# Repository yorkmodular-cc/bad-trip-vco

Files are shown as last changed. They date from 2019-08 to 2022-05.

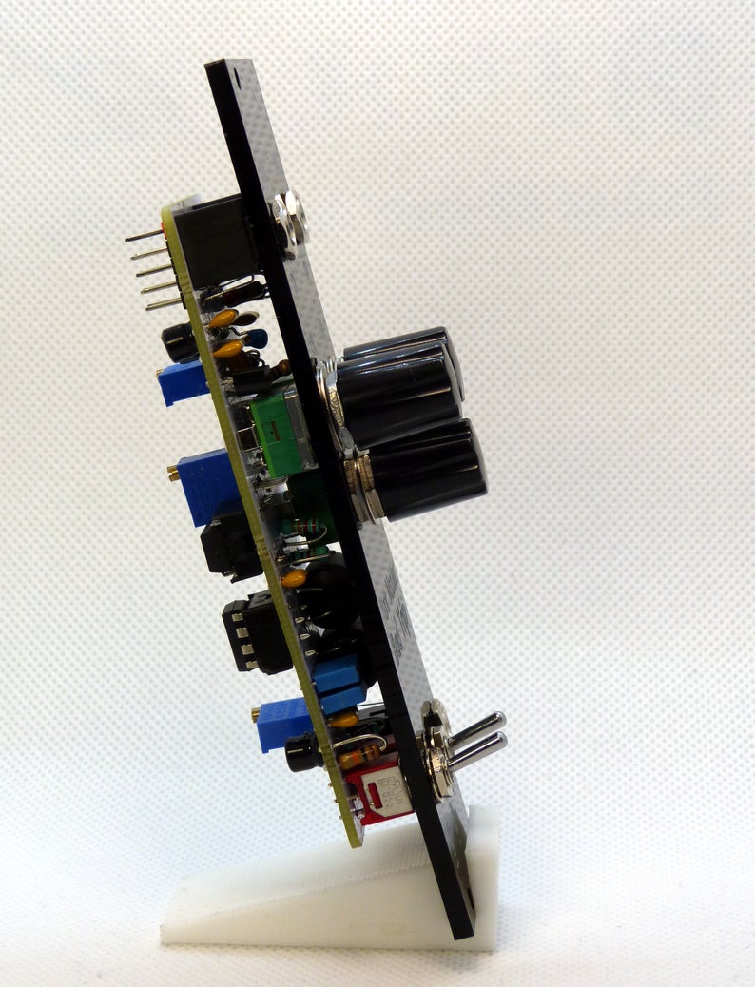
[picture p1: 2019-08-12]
images/il_794xN.1995096913_r65r.jpg

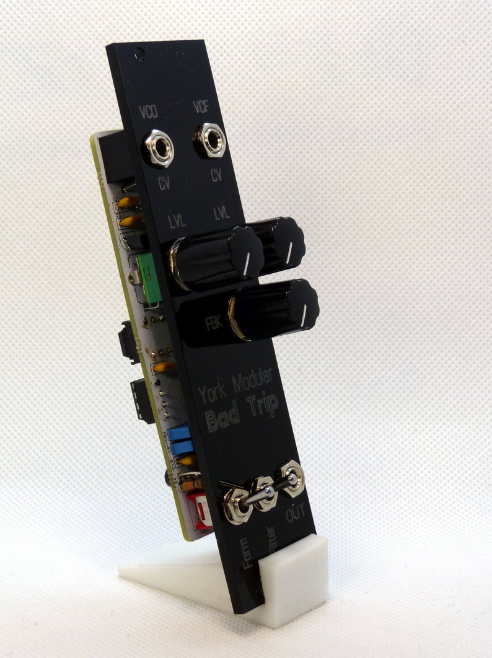
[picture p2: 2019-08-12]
images/il_794xN.1947558196_pjqa.jpg

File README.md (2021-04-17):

## York Modular 'Bad Trip' VCO

**This module is now discontinued - there will be no more made unless there is sufficient demand to justify a new run of boards and panels.**

**Information provided here is provided under the terms of the Creative Commons License Attribution-ShareAlike 4.0 International**

These are the files that you may (or may not) need for the Bad Trip VCO kit. It is assumed that you have enough knowledge to source appropriate components and read a schematic. 

Knowledge of how to use the Arduino IDE (or equivalent) to flash an ATTiny45/85 MCU is also desireable but not essential. In order to flash the firmware, your Arduino setup will need to include the ATTiny core by David Mellis - you can download that at https://github.com/damellis/attiny or install it via the Board Manager on newer versions of the Arduino IDE. As is, the default firmware will fit onto an ATTiny45 with space to spare - when flashing the firmware you'll need to specify the appropriate MCU with a 16MHz internal clock. Whilst there's absolutely no reason why you can't use a different clock speed, the frequency lookup table values assume a clock speed of 16MHz

The 'Bad Trip' is a square/saw VCO with a built in resonant vactrol filter - it gets it's name from the fact that you can coax some pretty squonky acid-style basslines out of it on the one hand, and utterly godawful nightmare noises on the other. 

More fun than it sounds, really.

Files included are:

- `badtrip-schematic.png` - the board schematic.
- `badtrip-bom.xlsx` - the Bill of Materials (BOM); this is a list of all the bits you'll need to complete the build.
- The `panels` directory contains design files for the front panel in AutoCAD (`.dxf`) and Schaeffer (`.fpd`) formats. You'll need these if you plan to fab your own panels.
- The `src` directory contains the firmware source file and a corresponding `.hex` file.
- `gerbers` contains the Gerber file for fabrication. These are what you want to be sending to the fab.

The firmware has a permissive license, so feel free to hack on it - all pull requests will be considered.

### Construction

There are no particular gotchas in terms of construction, however you should consider the following when setting the module up:

- Trimmer R7 controls the amount of current flowing into the two filter vactrols.
- Trimmers R10 and R11 affect the 'maximum' resistance of the two filter vactrols. They don't necessarily need to be trimmed to the same value - indeed, you'll get more interesting sounds out if they aren't.
- The effect of the feedback resistor will depend on the values of R10 and R11; in a lot of cases the response is somewhat 'digital' - if you're building from scratch then you can replace this pot with a wire link (and make sure you remove the corresponding hole from the panel)

### IMPORTANT

Since the VCO is microcontroller-based there are limits to the range of CV voltages that can be handled - anything negative is 'rejected' (ie. treated as 0V) whereas anything above 5V is clipped to 5V - the net result is that the VCO has a range of 5 octaves. Under most circumstances you'll want to have the CV pot fully clockwise, however if you're outputting particularly 'hot' CVs then you'll need to fiddle with the CV attenuator to bring the incoming CV down to something that the MCU can handle.

By default, the lowest note output by the VCO is C1 (32Hz) - you can alter this in firmware by modifying the frequency lookup table.

The tracking is pretty decent over 5 octaves but suffers a little due to the resolution of the ATTiny's ADC (10 bits) - this means that the input range is split into 1024 'divisions', with each division corresponding to around 4mV. If you want super-accurate to-the-cent tuning then you might well be disappointed, although you could probably fix things up in the firmware to a certain extent - this is where most of the work is done anyway.

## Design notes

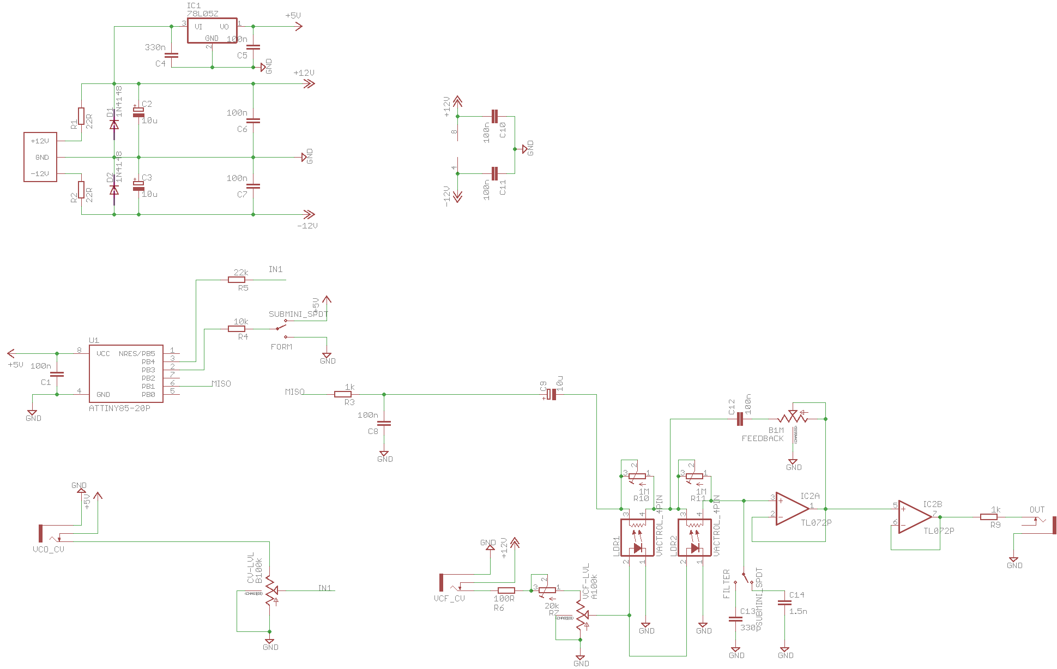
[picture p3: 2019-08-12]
badtrip-schematic.png

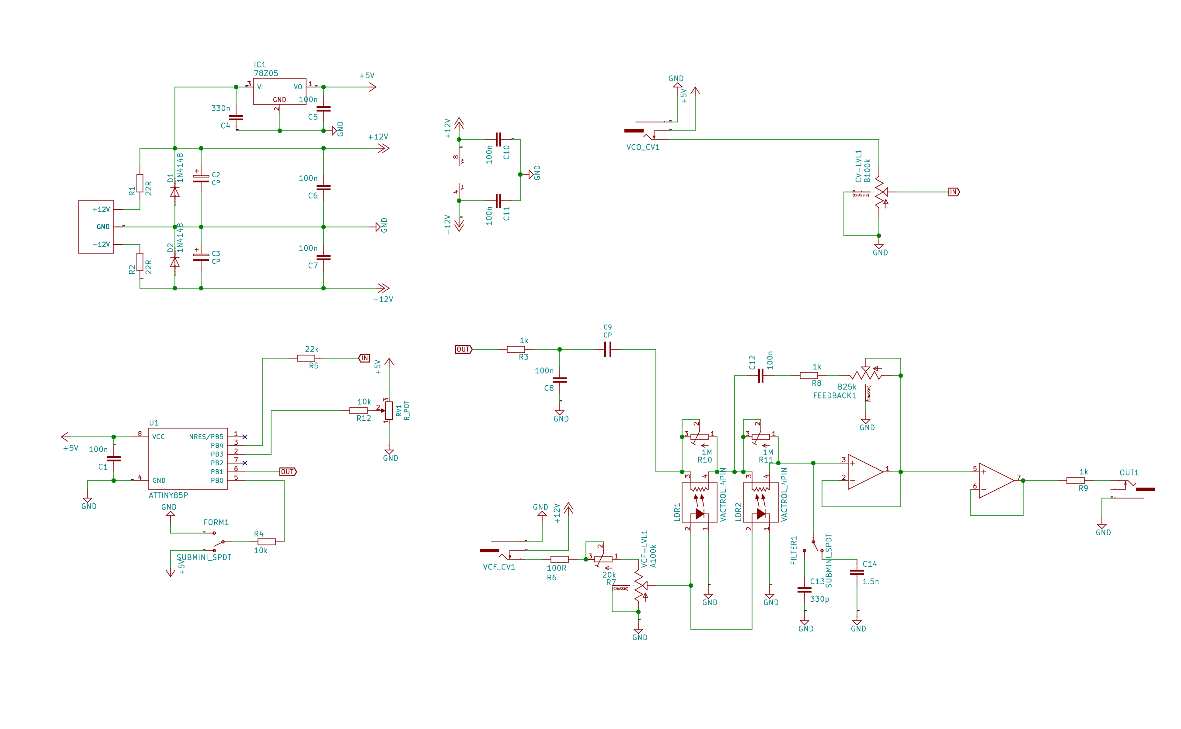
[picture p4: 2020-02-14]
v1.5/badtrip-1.5-schematic.png

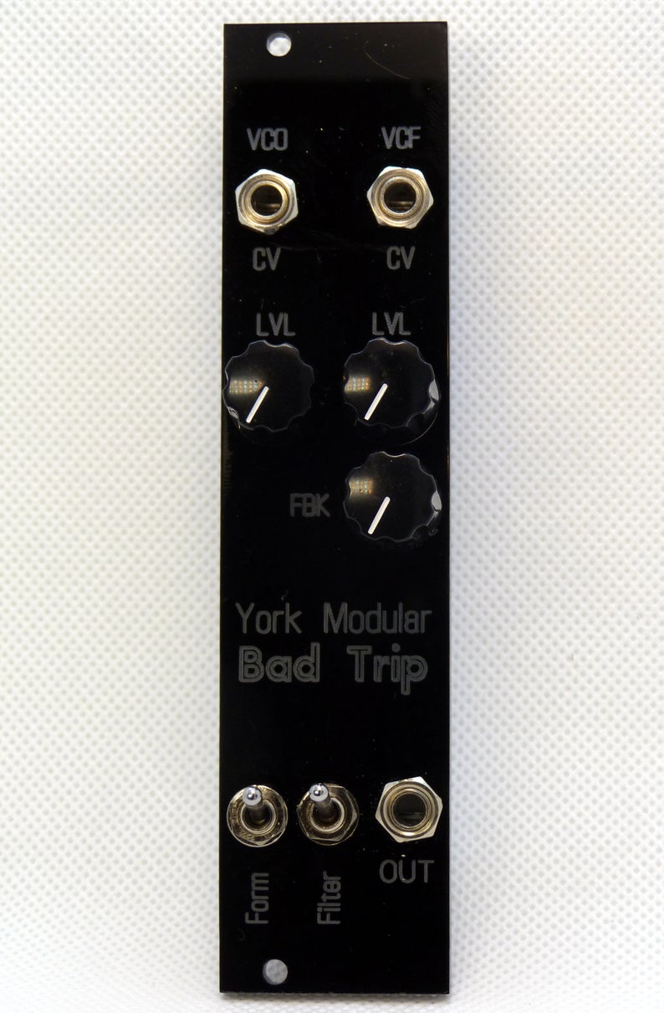
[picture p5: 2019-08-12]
images/il_794xN.1995097203_pyxm.jpg

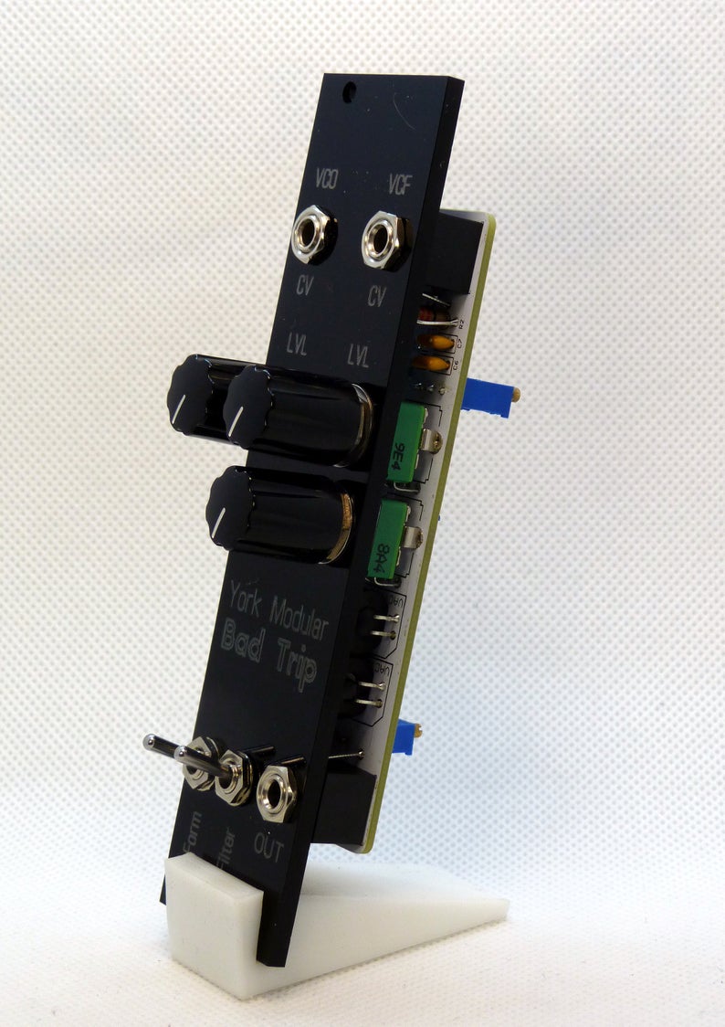
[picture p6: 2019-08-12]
images/il_794xN.1950445388_aedu.jpg

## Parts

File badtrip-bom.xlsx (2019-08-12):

Qty | Value | Device | Package | Parts | Description
1 | 1.5n | C-EU025-025X050 | C025-025X050 | C14 | CAPACITOR, European symbol
1 | 100R | R-EU_0207/2V | 0207/2V | R6 | RESISTOR, European symbol
6 | 100n | C-EU025-025X050 | C025-025X050 | C1, C5, C6, C7, C10, C11 | CAPACITOR, European symbol
2 | 100n | C-EU050-025X075 | C050-025X075 | C8, C12 | CAPACITOR, European symbol
1 | 10k | R-EU_0207/2V | 0207/2V | R4 | RESISTOR, European symbol
3 | 10u | CPOL-EUE2.5-5 | E2,5-5 | C2, C3, C9 | POLARIZED CAPACITOR, European symbol
2 | 1M | R-TRIMM3296W | RTRIM3296W | R10, R11 | Trimm resistor
2 | 1N4148 | DIODE-D-2.5 | D-2.5 | D1, D2 | DIODE
2 | 1k | R-EU_0207/2V | 0207/2V | R3, R9 | RESISTOR, European symbol
1 | 20k | R-TRIMM3296W | RTRIM3296W | R7 | Trimm resistor
2 | 22R | R-EU_0207/2V | 0207/2V | R1, R2 | RESISTOR, European symbol
1 | 22k | R-EU_0207/2V | 0207/2V | R5 | RESISTOR, European symbol
1 | 330n | C-EU025-025X050 | C025-025X050 | C4 | CAPACITOR, European symbol
1 | 330p | C-EU025-025X050 | C025-025X050 | C13 | CAPACITOR, European symbol
1 | 78L05Z | 78L05Z | TO92 | IC1 | Positive VOLTAGE REGULATOR
1 | A100k | 9MM_SNAP-IN_POT_CHASSIS | 9MM_SNAP-IN_POT | VCF-LVL | 9mm vertical snap-in pot, Alpha / Panasonic style, with a connection to the metal chassis for grounding
1 | ATTINY85-20P | ATTINY85-20P | PDIP08_300MIL | U1 | ATMEL ATtiny 85
1 | B100k | 9MM_SNAP-IN_POT_CHASSIS | 9MM_SNAP-IN_POT | CV-LVL | 9mm vertical snap-in pot, Alpha / Panasonic style, with a connection to the metal chassis for grounding
1 | B1M | 9MM_SNAP-IN_POT_CHASSIS | 9MM_SNAP-IN_POT | FEEDBACK | 9mm vertical snap-in pot, Alpha / Panasonic style, with a connection to the metal chassis for grounding
1 | EURO_POWER_LOCK | EURO_POWER_LOCK | EURO_PWR_HEADER_LOCK | LOCK1
2 | SUBMINI_SPDT | SUBMINI_SPDT | SUBMINI_TOGGLE | FILTER, FORM | Subminiature switches – solder pin connections, 2.54mm centres.
3 | THONKICONNNEW | THONKICONNNEW | WQP-PJ301M-12_JACK | OUT, VCF_CV, VCO_CV | 3.5mm socket for Eurorack modular synths
1 | TL072P | TL072P | DIL08 | IC2 | OP AMP
2 | VACTROL_4PIN | VACTROL_4PIN | VACTROL_4PIN_VTL5C | LDR1, LDR2 | 4 Pin Vactrol Resistive Photocoupler
 |  |  |  | NOTES: | C13/C14 are the two ‘main’ filter caps – lower values => ‘harsher’ sound.
 |  |  |  |  | R10 and R11 control the maximum resistance of the vactrols
 |  |  |  |  | R7 controls the current into the vactrols from the CV input – tweak R7, R10 and R11 to taste
 |  |  |  |  | Feedback pot can be omitted (use wire link) or replaced with a fixed resistor if desired.

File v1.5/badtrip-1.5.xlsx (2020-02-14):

Designator | Package | Quantity | Designation
C1,C11,C10,C7,C6,C5 | C_Disc_D5.0mm_W2.5mm_P2.50mm | 6 | 100n
RV1 | Potentiometer_Bourns_3314G_Vertical | 1 | R_POT
R12,R4 | R_Axial_DIN0207_L6.3mm_D2.5mm_P2.54mm_Vertical | 2 | 10k
R8,R9,R3 | R_Axial_DIN0207_L6.3mm_D2.5mm_P2.54mm_Vertical | 3 | 1k
LDR2,LDR1 | PerkinElmer_VTL5C | 2 | VACTROL_4PIN
R7 | Potentiometer_Bourns_3296W_Vertical | 1 | 20k
U1 | DIP-8_W7.62mm_Socket | 1 | ATTINY85P
IC2 | DIP-8_W7.62mm_Socket | 1 | TL072P
R11,R10 | Potentiometer_Bourns_3296W_Vertical | 2 | 1M
R6 | R_Axial_DIN0207_L6.3mm_D2.5mm_P2.54mm_Vertical | 1 | 100R
R5 | R_Axial_DIN0207_L6.3mm_D2.5mm_P2.54mm_Vertical | 1 | 22k
R2,R1 | R_Axial_DIN0207_L6.3mm_D2.5mm_P2.54mm_Vertical | 2 | 22R
IC1 | TO-92 | 1 | 78Z05
C12,C8 | C_Disc_D7.5mm_W2.5mm_P5.00mm | 2 | 100n
C9 | C_Disc_D5.0mm_W2.5mm_P2.50mm | 1 | CP
C3,C2 | CP_Radial_D5.0mm_P2.50mm | 2 | CP
C14 | C_Disc_D5.0mm_W2.5mm_P2.50mm | 1 | 1.5n
C13 | C_Disc_D5.0mm_W2.5mm_P2.50mm | 1 | 330p
C4 | C_Disc_D5.0mm_W2.5mm_P2.50mm | 1 | 330n
D1,D2 | D-2.5 | 2 | 1N4148
LOCK1 | EURO_PWR_HEADER_LOCK | 1 | EURO_POWER_LOCK
VCO_CV1,VCF_CV1,OUT1 | WQP-PJ301M-12_JACK | 3 | THONKICONNNEW
CV-LVL1 | 9MM_SNAP-IN_POT | 1 | B100k
FEEDBACK1 | 9MM_SNAP-IN_POT | 1 | B25k
VCF-LVL1 | 9MM_SNAP-IN_POT | 1 | A100k
FORM1,FILTER1 | SUBMINI_TOGGLE | 2 | SUBMINI_SPDT

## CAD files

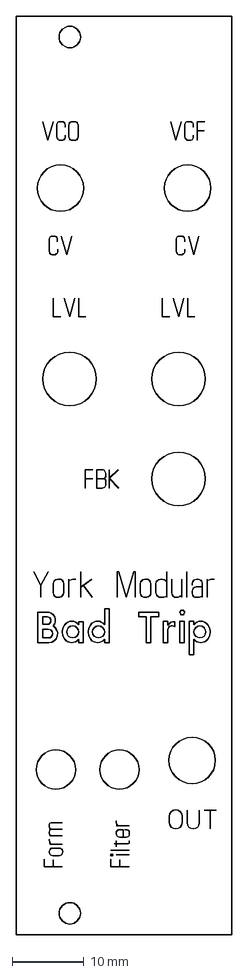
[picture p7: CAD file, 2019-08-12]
panels/bad-trip-lettered.dxf
30.1 x 128.4 mm

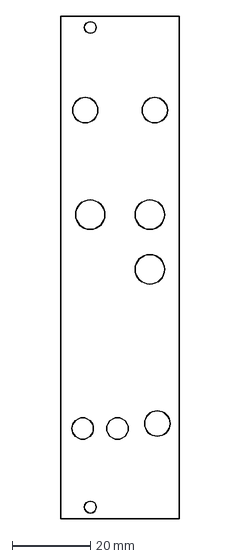
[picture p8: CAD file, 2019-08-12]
panels/bad-trip-blank.dxf
30.1 x 128.4 mm

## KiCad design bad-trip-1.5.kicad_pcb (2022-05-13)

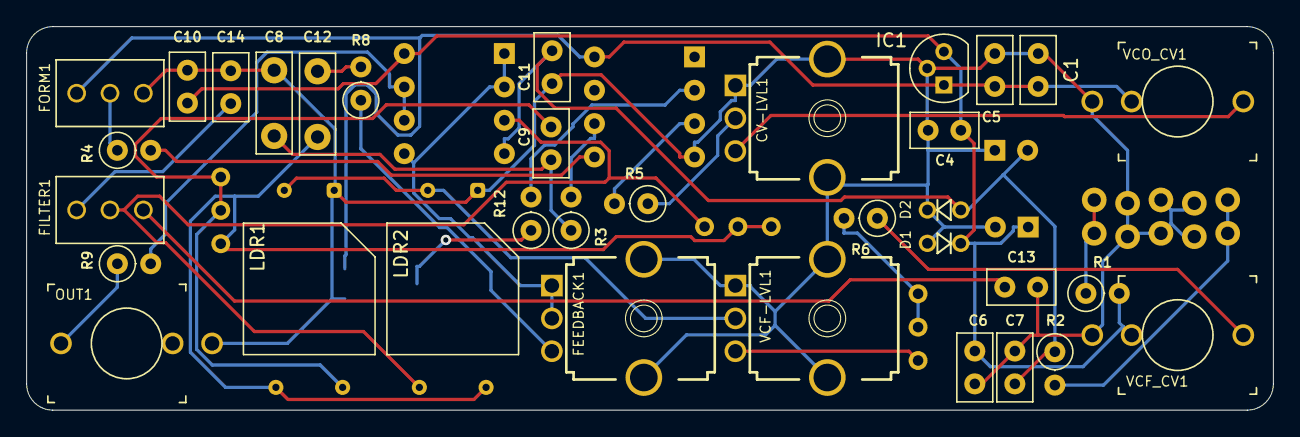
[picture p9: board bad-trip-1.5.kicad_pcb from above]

Board: 2 copper layers, 94.9 x 29.2 mm, 43 parts (0 on the bottom side), 29 nets.

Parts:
C1, C5, C6, C7, C10, C11: 100n; C_Disc_D5.0mm_W2.5mm_P2.50mm
C2, C3: CP; CP_Radial_D5.0mm_P2.50mm
C4: 330n; C_Disc_D5.0mm_W2.5mm_P2.50mm
C8, C12: 100n; C_Disc_D7.5mm_W2.5mm_P5.00mm
C9: CP; C_Disc_D5.0mm_W2.5mm_P2.50mm
C13: 330p; C_Disc_D5.0mm_W2.5mm_P2.50mm
C14: 1.5n; C_Disc_D5.0mm_W2.5mm_P2.50mm
CV-LVL1: B100k; 9MM_SNAP-IN_POT
D1, D2: 1N4148; D-2.5
FEEDBACK1: B1M; 9MM_SNAP-IN_POT
FILTER1: SUBMINI_SPDT; SUBMINI_TOGGLE
FORM1: SUBMINI_SPDT; SUBMINI_TOGGLE
IC1: 78Z05; TO-92
IC2: TL072P; DIP-8_W7.62mm_Socket
LDR1, LDR2: VACTROL_4PIN; PerkinElmer_VTL5C
LOCK1: EURO_POWER_LOCK; EURO_PWR_HEADER_LOCK
OUT1: THONKICONNNEW; WQP-PJ301M-12_JACK
R1, R2: 22R; R_Axial_DIN0207_L6.3mm_D2.5mm_P2.54mm_Vertical
R3, R8, R9: 1k; R_Axial_DIN0207_L6.3mm_D2.5mm_P2.54mm_Vertical
R4, R12: 10k; R_Axial_DIN0207_L6.3mm_D2.5mm_P2.54mm_Vertical
R5: 22k; R_Axial_DIN0207_L6.3mm_D2.5mm_P2.54mm_Vertical
R6: 100R; R_Axial_DIN0207_L6.3mm_D2.5mm_P2.54mm_Vertical
R7: 20k; Potentiometer_Bourns_3296W_Vertical
R10, R11: 1M; Potentiometer_Bourns_3296W_Vertical
RV1: R_POT; Potentiometer_Bourns_3314G_Vertical
U1: ATTINY85P; DIP-8_W7.62mm_Socket
VCF-LVL1: A100k; 9MM_SNAP-IN_POT
VCF_CV1: THONKICONNNEW; WQP-PJ301M-12_JACK
VCO_CV1: THONKICONNNEW; WQP-PJ301M-12_JACK

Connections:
+5V: C1.2, C5.2, FORM1.1, IC1.1, RV1.3, U1.8, VCO_CV1.P$2_SWITCH
+12V: C2.1, C4.2, C6.2, C10.2, D1.C, IC1.3, IC2.8, R1.2, VCF_CV1.P$2_SWITCH
-12V: C3.2, C7.1, C11.2, D2.A, IC2.4, R2.1
GND: C1.1, C2.2, C3.1, C4.1, C5.1, C6.1, C7.2, C8.1, C10.1, C11.1, C13.2, C14.2, CV-LVL1.1, CV-LVL1.CHASSIS1, CV-LVL1.CHASSIS2, D1.A, D2.C, FEEDBACK1.CHASSIS1, FEEDBACK1.CHASSIS2, FORM1.3, IC1.2, LDR1.1, LDR2.1, LOCK1.GND1, LOCK1.GND2, LOCK1.GND3, LOCK1.GND4, LOCK1.GND5, LOCK1.GND6, OUT1.P$3_SLEEVE, RV1.1, U1.4, VCF-LVL1.1, VCF-LVL1.CHASSIS1, VCF-LVL1.CHASSIS2, VCF_CV1.P$3_SLEEVE, VCO_CV1.P$3_SLEEVE
IN: CV-LVL1.2, R5.1
unnamed: C8.2, C9.2, R3.1
unnamed: C9.1, LDR1.3, R10.2, R10.3
unnamed: C12.1, LDR1.4, LDR2.3, R10.1, R11.2, R11.3
unnamed: C12.2, R8.2
unnamed: C13.1, FILTER1.3
unnamed: C14.1, FILTER1.1
unnamed: CV-LVL1.3, VCO_CV1.P$1_TIP
unnamed: FEEDBACK1.1, FEEDBACK1.2, IC2.1, IC2.2, IC2.5
unnamed: FEEDBACK1.3, R8.1
unnamed: FILTER1.COM, IC2.3, LDR2.4, R11.1
unnamed: FORM1.COM, R4.1
unnamed: IC2.6, IC2.7, R9.2
unnamed: LDR1.2, LDR2.2, VCF-LVL1.2
unnamed: LOCK1.NEG1, LOCK1.NEG2, R2.2
unnamed: LOCK1.POS1, LOCK1.POS2, R1.1
unnamed: OUT1.P$1_TIP, R9.1
unnamed: R4.2, U1.5
unnamed: R5.2, U1.3
unnamed: R6.1, VCF_CV1.P$1_TIP
unnamed: R6.2, R7.2, R7.3
unnamed: R7.1, VCF-LVL1.3
unnamed: R12.1, RV1.2
unnamed: R12.2, U1.2
OUT: R3.2, U1.6

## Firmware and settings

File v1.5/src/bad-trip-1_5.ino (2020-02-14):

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
// Firmware for AVR-based wavetable VCOs.
// Written by Simon Ward <simon@yorkmodular.co.uk>
//
#include <avr/io.h>
#include <avr/interrupt.h>
#include <avr/pgmspace.h>

// Wavetable definitions - values are defined in wavetables.h
#define WAVETABLE_SAW         0
#define WAVETABLE_SQUARE      1
#define CV_INPUT              A2  // PB4 (pin 3)
#define WAVE_INPUT            PB0  // PB0 (pin 5)
#define TUNE_INPUT            A3 //
#define WAVETABLE_LENGTH      256
#define MAPTABLE_LENGTH       1024

// 1V/octave lookup table - the values are phase increments. Base frequency is
// approximately 30Hz.
const uint16_t freqTable[MAPTABLE_LENGTH] PROGMEM = {
    69,69,69,69,70,70,70,70,70,71,71,71,71,72,72,72,72,73,73,73,73,74,74,74,
    74,75,75,75,75,76,76,76,76,77,77,77,77,78,78,78,79,79,79,79,80,80,80,80,
    81,81,81,81,82,82,82,83,83,83,83,84,84,84,85,85,85,85,86,86,86,87,87,87,
    88,88,88,88,89,89,89,90,90,90,91,91,91,91,92,92,92,93,93,93,94,94,94,95,
    95,95,96,96,96,97,97,97,98,98,98,99,99,99,100,100,100,101,101,101,102,102,
    102,103,103,103,104,104,104,105,105,105,106,106,106,107,107,108,108,108,
    109,109,109,110,110,111,111,111,112,112,112,113,113,114,114,114,115,115,
    115,116,116,117,117,117,118,118,119,119,119,120,120,121,121,122,122,122,
    123,123,124,124,124,125,125,126,126,127,127,127,128,128,129,129,130,130,
    130,131,131,132,132,133,133,134,134,134,135,135,136,136,137,137,138,138,
    139,139,140,140,141,141,141,142,142,143,143,144,144,145,145,146,146,147,
    147,148,148,149,149,150,150,151,151,152,152,153,153,154,155,155,156,156,
    157,157,158,158,159,159,160,160,161,161,162,163,163,164,164,165,165,166,
    166,167,168,168,169,169,170,170,171,172,172,173,173,174,175,175,176,176,
    177,178,178,179,179,180,181,181,182,182,183,184,184,185,185,186,187,187,
    188,189,189,190,191,191,192,193,193,194,194,195,196,196,197,198,198,199,
    200,201,201,202,203,203,204,205,205,206,207,207,208,209,210,210,211,212,
    212,213,214,215,215,216,217,217,218,219,220,220,221,222,223,223,224,225,
    226,226,227,228,229,230,230,231,232,233,233,234,235,236,237,237,238,239,
    240,241,242,242,243,244,245,246,246,247,248,249,250,251,252,252,253,254,
    255,256,257,258,258,259,260,261,262,263,264,265,266,266,267,268,269,270,
    271,272,273,274,275,276,277,277,278,279,280,281,282,283,284,285,286,287,
    288,289,290,291,292,293,294,295,296,297,298,299,300,301,302,303,304,305,
    306,307,308,309,310,311,312,313,314,316,317,318,319,320,321,322,323,324,
    325,326,328,329,330,331,332,333,334,335,337,338,339,340,341,342,343,345,
    346,347,348,349,350,352,353,354,355,356,358,359,360,361,363,364,365,366,
    367,369,370,371,372,374,375,376,378,379,380,381,383,384,385,387,388,389,
    391,392,393,395,396,397,399,400,401,403,404,405,407,408,410,411,412,414,
    415,417,418,419,421,422,424,425,426,428,429,431,432,434,435,437,438,440,
    441,443,444,446,447,449,450,452,453,455,456,458,459,461,463,464,466,467,
    469,470,472,474,475,477,479,480,482,483,485,487,488,490,492,493,495,497,
    498,500,502,503,505,507,509,510,512,514,515,517,519,521,523,524,526,528,
    530,531,533,535,537,539,541,542,544,546,548,550,552,553,555,557,559,561,
    563,565,567,569,571,573,574,576,578,580,582,584,586,588,590,592,594,596,
    598,600,602,604,606,608,611,613,615,617,619,621,623,625,627,629,632,634,
    636,638,640,642,645,647,649,651,653,656,658,660,662,664,667,669,671,674,
    676,678,680,683,685,687,690,692,694,697,699,701,704,706,709,711,713,716,
    718,721,723,726,728,730,733,735,738,740,743,745,748,751,753,756,758,761,
    763,766,769,771,774,776,779,782,784,787,790,792,795,798,800,803,806,809,
    811,814,817,820,822,825,828,831,834,836,839,842,845,848,851,854,856,859,
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
};

volatile uint16_t syncPhaseAcc, syncPhaseInc, baseFreq, syncOffset, finetune;
volatile uint8_t current_wavetable = 0;

uint16_t mapFreq(uint16_t input) {
  return pgm_read_word_near(freqTable + input);
}
uint16_t acc, a1_level, buff_step;

void audioOn() {
  PLLCSR = 1 << PCKE | 1 << PLLE;
  TIMSK = 0;
  TCCR1 = 1 << PWM1A | 2 << COM1A0 | 1 << CS11;
  OCR1A = 128;
  pinMode(1, OUTPUT);
  pinMode(CV_INPUT, INPUT);
  pinMode(WAVE_INPUT, INPUT);
  pinMode(TUNE_INPUT, INPUT);

  TCCR0A = (1 << WGM00) | (1 << WGM01);
  TCCR0B = 1 << WGM02 | 2 << CS00;
  TIMSK = 1 << OCIE0A; // Compare match A
  OCR0A = 29;
  syncPhaseAcc = 0;
}

void setup() {
  audioOn();
}

void loop() {
  // Desired frequency - resolution is 5V / 1024 steps = 4.8mV
  // The lookup table for mapFreq yields a response pretty close to 1V/oct
  baseFreq = mapFreq(analogRead(CV_INPUT));
  current_wavetable = (digitalRead(WAVE_INPUT) == HIGH) ? WAVETABLE_SAW : WAVETABLE_SQUARE ;
  finetune = -64 + (analogRead(TUNE_INPUT) >> 3);
  syncPhaseInc = baseFreq + finetune;
}

// The interrupt service routine - this is where it all happens.
//
// On the ATTiny85, there's a conflict relating to TIMER0_OVF_vect in
// some cores so we use the comparator instead. The net result is the
// same.
//
// - Increment the phase accumulator
// - Convert the accumulator value to an 8-bit number corresponding to
//   the step in the wavetable
// - Read the appropriate wavetable value
// - Write it to the PWM pinf

ISR(TIMER0_COMPA_vect) {
   uint8_t val, step, phased_step;

   syncPhaseAcc += syncPhaseInc;

   step = syncPhaseAcc >> 8;
   switch (current_wavetable) {
     case WAVETABLE_SAW:
         val = step & 0xff;
         break;
     default:
         val = ( step <= 128) ? 0xff : 0x00;
         break;
   }
   OCR1A = val;
}

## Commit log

2020-02-14 Files for v1.5 revision
    [badtrip-1.5.xlsx]
2021-04-17 Add Gerber files
    [BadTrip-B_Mask.gbs, BadTrip-B_Paste.gbp, BadTrip-B_Silk.gbo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]
